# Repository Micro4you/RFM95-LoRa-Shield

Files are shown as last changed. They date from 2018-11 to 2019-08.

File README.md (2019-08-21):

# RFM95 LoRa Shield V0.2

ดาวน์โหลด คู่มือการเชื่อมต่อเข้าระบบ LoRa IoT by CAT ฉบับ Official ได้จาก https://drive.google.com/file/d/1OALHqggIONH6ys-gYKr0pkf06lvrriyg/view

// Pin mapping

const lmic_pinmap lmic_pins = {

  .nss = 10,
  
  .rxtx = LMIC_UNUSED_PIN,
  
  .rst = 9,
  
  .dio = {2, 6, 7},
  
 ** AS923-upper (923.2-924.6MHz) LMIC-arduino code https://github.com/promwungkwa/LMIC-Arduino-AS923-upper

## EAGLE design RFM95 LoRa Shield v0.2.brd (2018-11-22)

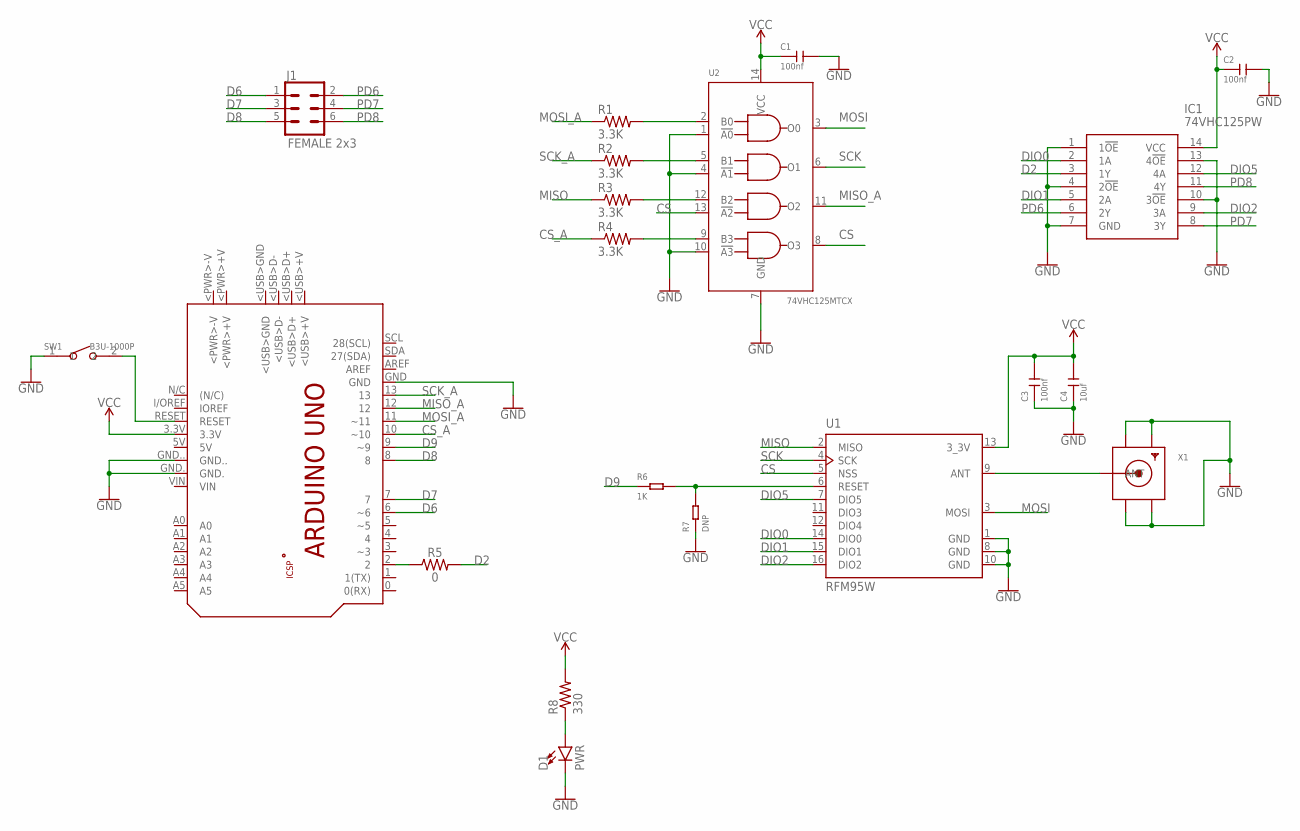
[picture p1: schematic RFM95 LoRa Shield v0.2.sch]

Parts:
C1, C2, C3: 100nf; C0805
C4: 10uf; C0805
D1: PWR; LED-1206
IC1: 74VHC125PW; SOP65P640X110-14N
J1: FEMALE 2x3; 2X3
PCB1: Arduino Uno; ARDUINO_UNO
R1, R2, R3, R4: 3.3K; M0805
R5: 0; 0603
R6: 1K; R0805
R7: DNP; R0805
R8: 330; M0805
SW1: B3U-1000P; SW2-2.6-3.0X2.5X1.2+0.4MM
U1: RFM95W; XCVR_RFM95W-868S2
U2: 74VHC125MTCX; TSSOP14-0.65-5X4.4MM
X1: SMACONNECTOR; SMA90_DIP

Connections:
CS: U1.5 (NSS), U2.8 (O3), U2.13 (!A2)
CS_A: PCB1.10 (~10), R4.1
D2: IC1.3 (1Y), R5.2
D6: J1.1, PCB1.6 (~6)
D7: J1.3, PCB1.7
D8: J1.5, PCB1.8
D9: PCB1.9 (~9), R6.1
DIO0: IC1.2 (1A), U1.14 (DIO0)
DIO1: IC1.5 (2A), U1.15 (DIO1)
DIO2: IC1.9 (3A), U1.16 (DIO2)
DIO5: IC1.12 (4A), U1.7 (DIO5)
GND: C1.2, C2.2, C3.1, C4.1, D1.C, IC1.1 (1!OE), IC1.4 (2!OE), IC1.7 (GND), IC1.10 (3!OE), IC1.13 (4!OE), PCB1.GND, PCB1.GND., PCB1.GND.., R7.1, SW1.1, U1.1 (GND), U1.8 (GND), U1.10 (GND), U2.1 (!A0), U2.4 (!A1), U2.7 (GND), U2.10 (!A3), X1.GND1, X1.GND2, X1.GND3, X1.GND4
MISO: R3.1, U1.2 (MISO)
MISO_A: PCB1.12, U2.11 (O2)
MOSI: U1.3 (MOSI), U2.3 (O0)
MOSI_A: PCB1.11 (~11), R1.1
unnamed: R1.2, U2.2 (B0)
unnamed: R2.2, U2.5 (B1)
unnamed: R3.2, U2.12 (B2)
unnamed: R4.2, U2.9 (B3)
unnamed: PCB1.2, R5.1
unnamed: R6.2, R7.2, U1.6 (RESET)
unnamed: U1.9 (ANT), X1.ANTENNA (ANT)
unnamed: PCB1.RESET, SW1.2
unnamed: D1.A, R8.1
PD6: IC1.6 (2Y), J1.2
PD7: IC1.8 (3Y), J1.4
PD8: IC1.11 (4Y), J1.6
SCK: U1.4 (SCK), U2.6 (O1)
SCK_A: PCB1.13, R2.1
VCC: C1.1, C2.1, C3.2, C4.2, IC1.14 (VCC), PCB1.3.3V, R8.2, U1.13 (3_3V), U2.14 (VCC)

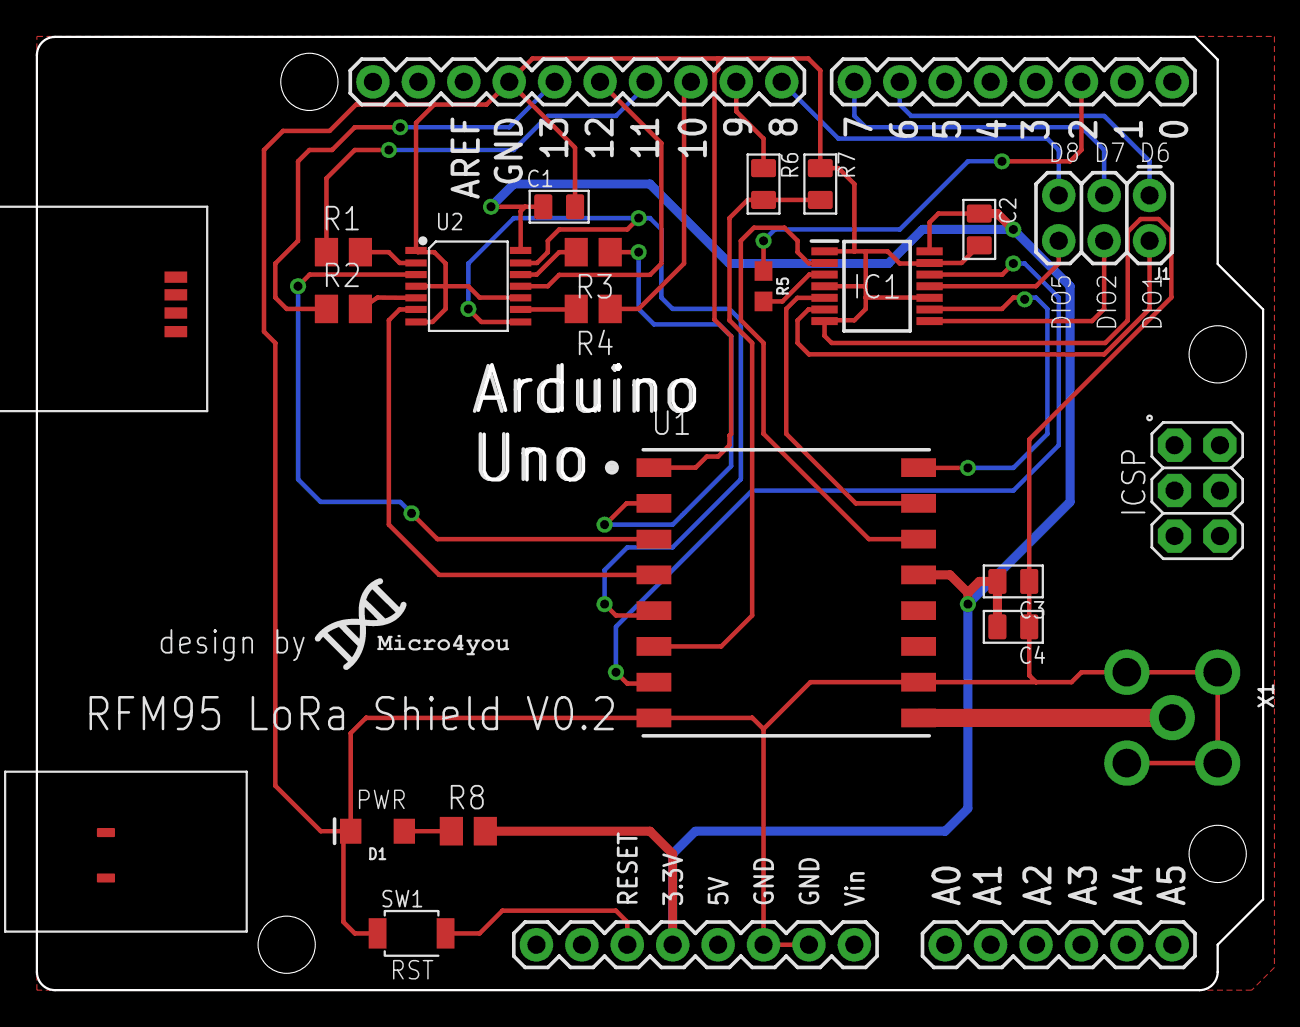
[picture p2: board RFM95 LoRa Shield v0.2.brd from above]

Board: 2 copper layers, 68.6 x 53.3 mm, 20 parts (0 on the bottom side), 31 nets.

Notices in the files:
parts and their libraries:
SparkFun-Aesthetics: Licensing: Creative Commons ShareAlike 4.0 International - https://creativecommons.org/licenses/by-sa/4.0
